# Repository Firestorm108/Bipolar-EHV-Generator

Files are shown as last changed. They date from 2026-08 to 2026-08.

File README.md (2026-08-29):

# Bipolar-EHV-Generator
An extreme high voltage generator that utilizes a bipolar setup to effectively create a 300kV+ voltage difference.

Assembly_2026-Aug-29_12-14-39AM-000_CustomizedView10577367450

# How does it work?

The custom ZVS driver drives the self-wound HV AC transformer. That transformer is connected to both inputs of voltage mulitpliers.
By configuring each multiplier to output a +HV and the other to do a -HV, it is no longer a +HV - GND difference, but +HV -HV difference.

Screenshot 2026-08-28 at 5 43 17 PM

# PCB Pictures

Screenshot 2026-08-28 at 5 44 21 PM
Screenshot 2026-08-28 at 5 44 59 PM

# Bill of Materials

| Item | Price | Link |
| --- | ---: | --- |
| White PLA | $13 | [Amazon](https://www.amazon.com/SUNLU-Printer-Filament-1-75mm-Printers/dp/B0BD7K5SQK/) |
| Kapton Tape | $10 | [Amazon](https://www.amazon.com/Hxtape-Temperature-Polyimide-Printing-Soldering/dp/B07D5RRXTS/) |
| 32 AWG Magnet Wire | $13 | [Amazon](https://www.amazon.com/BNTECHGO-AWG-Magnet-Wire-Transformers/dp/B07JBQQR38/) |
| Transformer Core | $23 | [Amazon](https://www.amazon.com/5pairs-UY1658-Transformer-ferrite-Material/dp/B0146OG8VK/r) |
| 16 AWG | $8 | [Amazon](https://www.amazon.com/Silicone-Electrical-Cable%EF%BC%8810ft-Temperature-Resistant/dp/B0D93K21TN/) |
| Momentary Push Button | $3 | [AliExpress](https://www.aliexpress.us/item/3256812230348809.html) |
| 40 × 2CL77 Diodes | $13 | [AliExpress](https://www.aliexpress.us/item/3256802425242911.html) |
| 40 × 20 kV 1 nF Capacitors | $14 | [AliExpress](https://www.aliexpress.us/item/3256809649447491.html) |
| 24 V 20 A SMPS | $22 | [Amazon](https://www.amazon.com/HPMN-24V-15A-360W-Transformer/dp/B0DPKJPB5P) |
| Mains Cable | $4 | [AliExpress](https://www.aliexpress.us/item/3256802936747637.html) |
| IRFP250 MOSFETs | $6 | [AliExpress](https://www.aliexpress.us/item/3256806932452420.html) |
| 470 Ω 2 W Resistors | $2 | [AliExpress](https://www.aliexpress.us/item/3256802900888178.html) |
| 0.47 µH 10 A Inductor | $6 | [AliExpress](https://www.aliexpress.us/item/3256806537093956.html) |
| 2-Pin Screw Terminals | $3 | [AliExpress](https://www.aliexpress.us/item/3256806674476213.html) |
| 3-Pin Screw Terminals | $4 | [AliExpress](https://www.aliexpress.us/item/3256806674476213.html) |
| 1N4742A 12 V Zener Diodes | $1 | [AliExpress](https://www.aliexpress.us/item/2255799836200735.html) |
| UF4007 400 V Fast-Switching Diodes | $2 | [AliExpress](https://www.aliexpress.us/item/2255800018624086.html) |
| 0.68 µF Film Capacitors | $3 | [AliExpress](https://www.aliexpress.us/item/3256801916333851.html) |
| 50 V 1000 µF Electrolytics | $5 | [AliExpress](https://www.aliexpress.us/item/3256811625053645.html) |
| Multiplier PCB | $8 | JLCPCB |
| ZVS PCB | $16 | JLCPCB |
| JLC Shipping | $15 | JLCPCB |
| **Total** | **$194** | |

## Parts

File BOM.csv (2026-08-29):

Item | Price | Link
White PLA | $13 | https://www.amazon.com/SUNLU-Printer-Filament-1-75mm-Printers/dp/B0BD7K5SQK/
Kapton Tape | $10 | https://www.amazon.com/Hxtape-Temperature-Polyimide-Printing-Soldering/dp/B07D5RRXTS/
32AWG Magnet Wire | $13 | https://www.amazon.com/BNTECHGO-AWG-Magnet-Wire-Transformers/dp/B07JBQQR38/
Transformer Core | $23 | https://www.amazon.com/5pairs-UY1658-Transformer-ferrite-Material/dp/B0146OG8VK/r
16 AWG | $8 | https://www.amazon.com/Silicone-Electrical-Cable%EF%BC%8810ft-Temperature-Resistant/dp/B0D93K21TN/
Momentary Push Button | $3 | https://www.aliexpress.us/item/3256812230348809.html?
40 2CL77 Diodes | $13 | https://www.aliexpress.us/item/3256802425242911.html
40 20kV 1nF Capacitors | $14 | https://www.aliexpress.us/item/3256809649447491.html
24V 20A SMPS | $22 | https://www.amazon.com/HPMN-24V-15A-360W-Transformer/dp/B0DPKJPB5P
Mains Cable | $4 | https://www.aliexpress.us/item/3256802936747637.html
IRFP250 MOSFETs | $6 | https://www.aliexpress.us/item/3256806932452420.html?
470 Ohm 2W Resistors | $2 | https://www.aliexpress.us/item/3256802900888178.html?
0.47uH 10A Inductor | $6 | https://www.aliexpress.us/item/3256806537093956.html
2 Pin Screw Terminals | $3 | https://www.aliexpress.us/item/3256806674476213.html
3 Pin Screw Terminals | $4 | https://www.aliexpress.us/item/3256806674476213.html
1N4742A 12V Zener Diodes | $1 | https://www.aliexpress.us/item/2255799836200735.html?
UF4007 400V Fast Switching Diodes | $2 | https://www.aliexpress.us/item/2255800018624086.html?
0.68uF Film Capacitors | $3 | https://www.aliexpress.us/item/3256801916333851.html
50V 1000uF Electrolytics | $5 | https://www.aliexpress.us/item/3256811625053645.html?
Multiplier PCB | $8 | JLCPCB
ZVS PCB | $16 | JLCPCB
JLC Shipping | $15 | JLCPCB
Total | $194

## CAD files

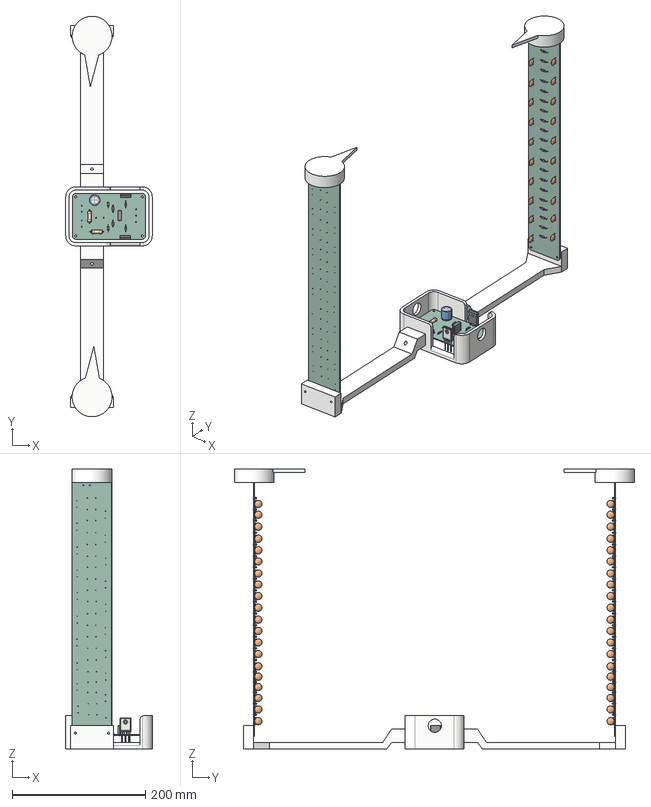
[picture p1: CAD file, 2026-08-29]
Assembly.step
130.1 x 602.1 x 421.0 mm

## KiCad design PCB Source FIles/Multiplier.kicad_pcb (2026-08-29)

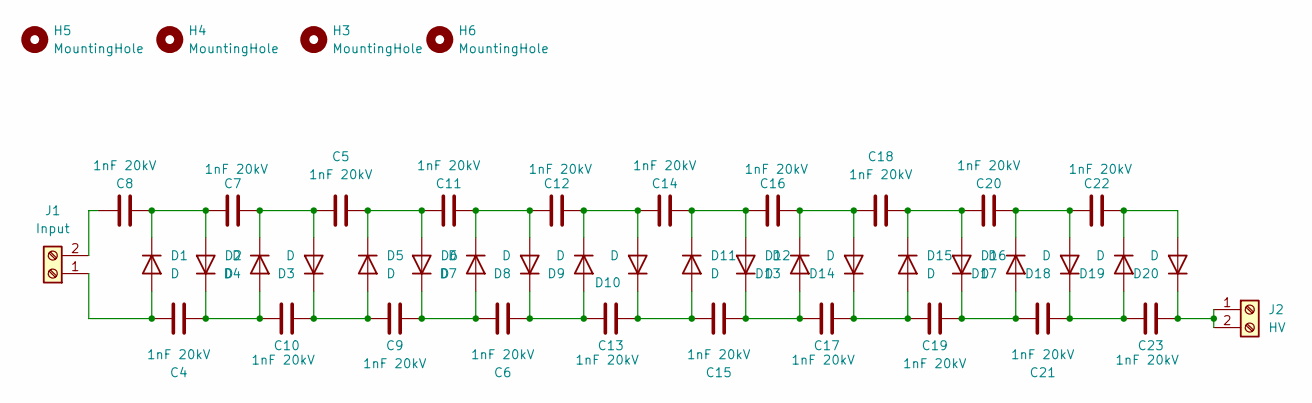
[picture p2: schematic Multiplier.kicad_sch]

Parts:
C4, C5, C6, C7, C8, C9, C10, C11, C12, C13, C14, C15, C16, C17, C18, C19, C20, C21, C22, C23: 1nF 20kV; C_Disc_D11.0mm_W5.0mm_P10.00mm
D1, D2, D3, D4, D5, D6, D7, D8, D9, D10, D11, D12, D13, D14, D15, D16, D17, D18, D19, D20: D; D_DO-41_SOD81_P12.70mm_Horizontal
H3, H4, H5, H6: MountingHole; MountingHole_3.2mm_M3
J1: Input; CONN-TH_2P-P9.50_HB9500-9.5-2P
J2: HV; CONN-TH_2P-P9.50_HB9500-9.5-2P

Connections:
unnamed: C4.2, D1.2 (A), J1.1
unnamed: C7.2, C8.1, D1.1 (K), D2.2 (A)
unnamed: C4.1, C10.1, D2.1 (K), D4.2 (A)
unnamed: C5.1, C7.1, D3.2 (A), D4.1 (K)
unnamed: C9.1, C10.2, D3.1 (K), D5.2 (A)
unnamed: C5.2, C11.2, D5.1 (K), D6.2 (A)
unnamed: C6.2, C9.2, D6.1 (K), D7.2 (A)
unnamed: C11.1, C12.2, D7.1 (K), D8.2 (A)
unnamed: C6.1, C13.1, D8.1 (K), D9.2 (A)
unnamed: C12.1, C14.2, D9.1 (K), D10.2 (A)
unnamed: C13.2, C15.2, D10.1 (K), D11.2 (A)
unnamed: C14.1, C16.2, D11.1 (K), D12.2 (A)
unnamed: C15.1, C17.1, D12.1 (K), D13.2 (A)
unnamed: C16.1, C18.1, D13.1 (K), D14.2 (A)
unnamed: C17.2, C19.1, D14.1 (K), D15.2 (A)
unnamed: C18.2, C20.2, D15.1 (K), D16.2 (A)
unnamed: C19.2, C21.2, D16.1 (K), D17.2 (A)
unnamed: C20.1, C22.2, D17.1 (K), D18.2 (A)
unnamed: C21.1, C23.1, D18.1 (K), D19.2 (A)
unnamed: C22.1, D19.1 (K), D20.2 (A)
unnamed: C23.2, D20.1 (K), J2.1, J2.2
unnamed: C8.2, J1.2

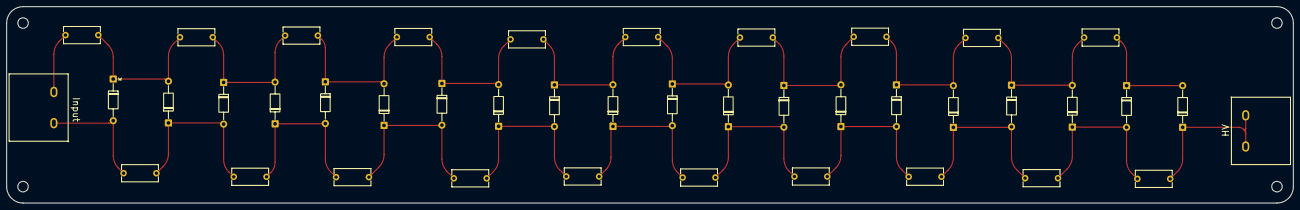
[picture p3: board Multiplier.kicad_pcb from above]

Board: 2 copper layers, 392.1 x 59.8 mm, 46 parts (0 on the bottom side), 22 nets.

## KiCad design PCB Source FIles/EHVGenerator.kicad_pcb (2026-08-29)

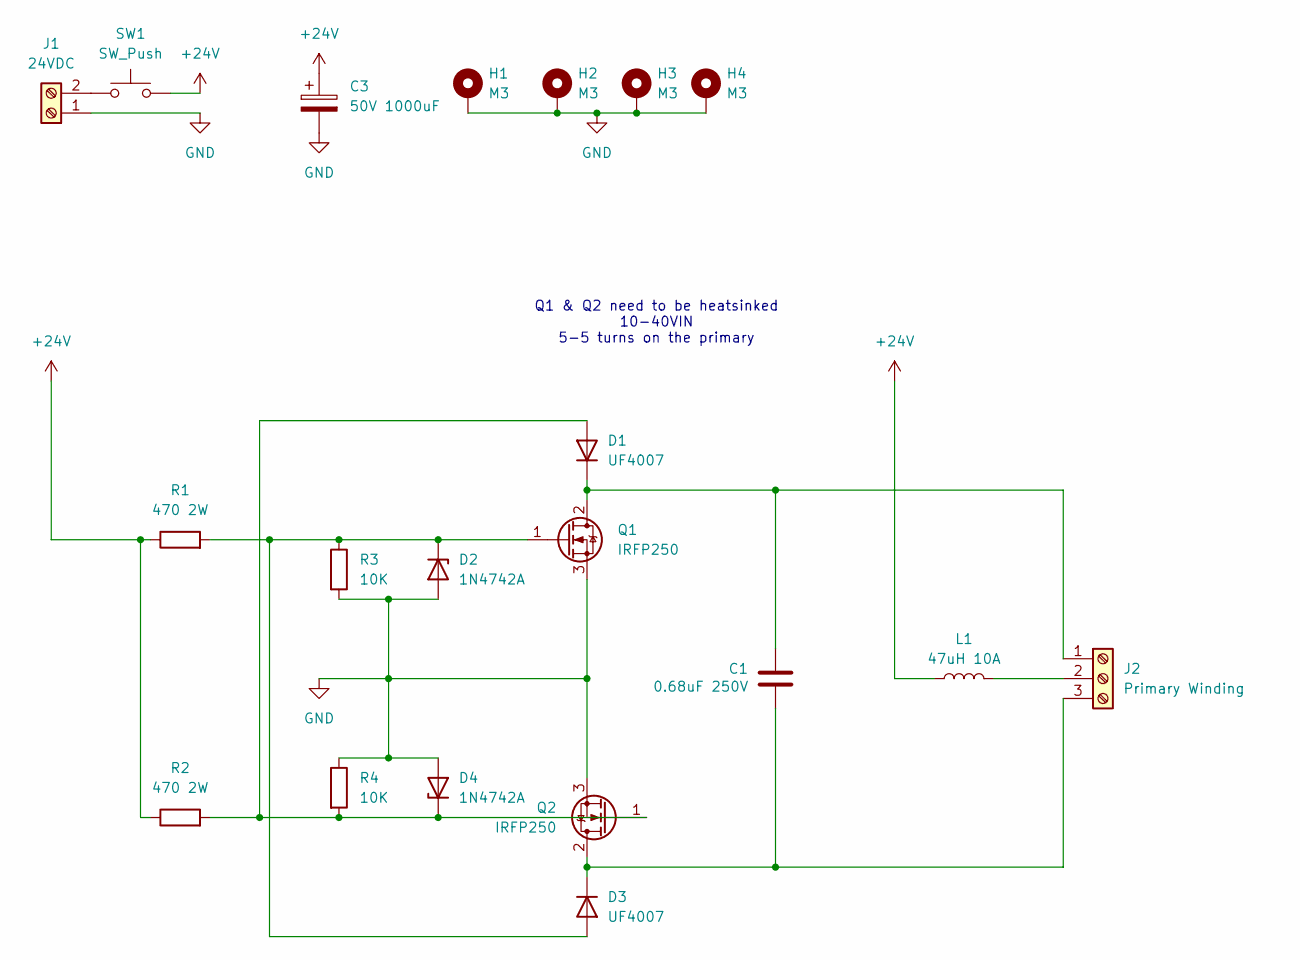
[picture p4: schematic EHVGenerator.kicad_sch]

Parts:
C1: 0.68uF 250V; C_Rect_L16.5mm_W5.0mm_P15.00mm_MKT
C3: 50V 1000uF; CP_Radial_D16.0mm_P7.50mm
D1, D3: UF4007; D_DO-41_SOD81_P10.16mm_Horizontal
D2, D4: 1N4742A; D_DO-41_SOD81_P10.16mm_Horizontal
H1, H2, H3, H4: M3; MountingHole_3.2mm_M3_Pad
J1: 24VDC; CONN-TH_2P-P9.50_HB9500-9.5-2P
J2: Primary Winding; CONN-TH_3P-P9.50_HB9500-9.5-3P
L1: 47uH 10A; L_Toroid_Vertical_L28.6mm_W14.3mm_P11.43mm_Bourns_5700
Q1, Q2: IRFP250; TO-247-3_Vertical
R1, R2: 470 2W; R_Axial_DIN0617_L17.0mm_D6.0mm_P20.32mm_Horizontal
R3, R4: 10K; R_Axial_DIN0207_L6.3mm_D2.5mm_P10.16mm_Horizontal
SW1: SW_Push; CONN-TH_2P-P9.50_HB9500-9.5-2P

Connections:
+24V: C3.1, L1.1, R1.1, R2.1, SW1.2
GND: C3.2, D2.2 (A), D4.2 (A), H1.1 (1_1), H2.1 (1_1), H3.1 (1_1), H4.1 (1_1), J1.1, Q1.3 (S), Q2.3 (S), R3.2, R4.1
unnamed: D1.2 (A), D4.1 (K), Q2.1 (G), R2.2, R4.2
unnamed: C1.2, D1.1 (K), J2.1, Q1.2 (D)
unnamed: D2.1 (K), D3.2 (A), Q1.1 (G), R1.2, R3.1
unnamed: C1.1, D3.1 (K), J2.3, Q2.2 (D)
unnamed: J1.2, SW1.1
unnamed: J2.2, L1.2

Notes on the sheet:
Q1 & Q2 need to be heatsinked 10-40VIN 5-5 turns on the primary

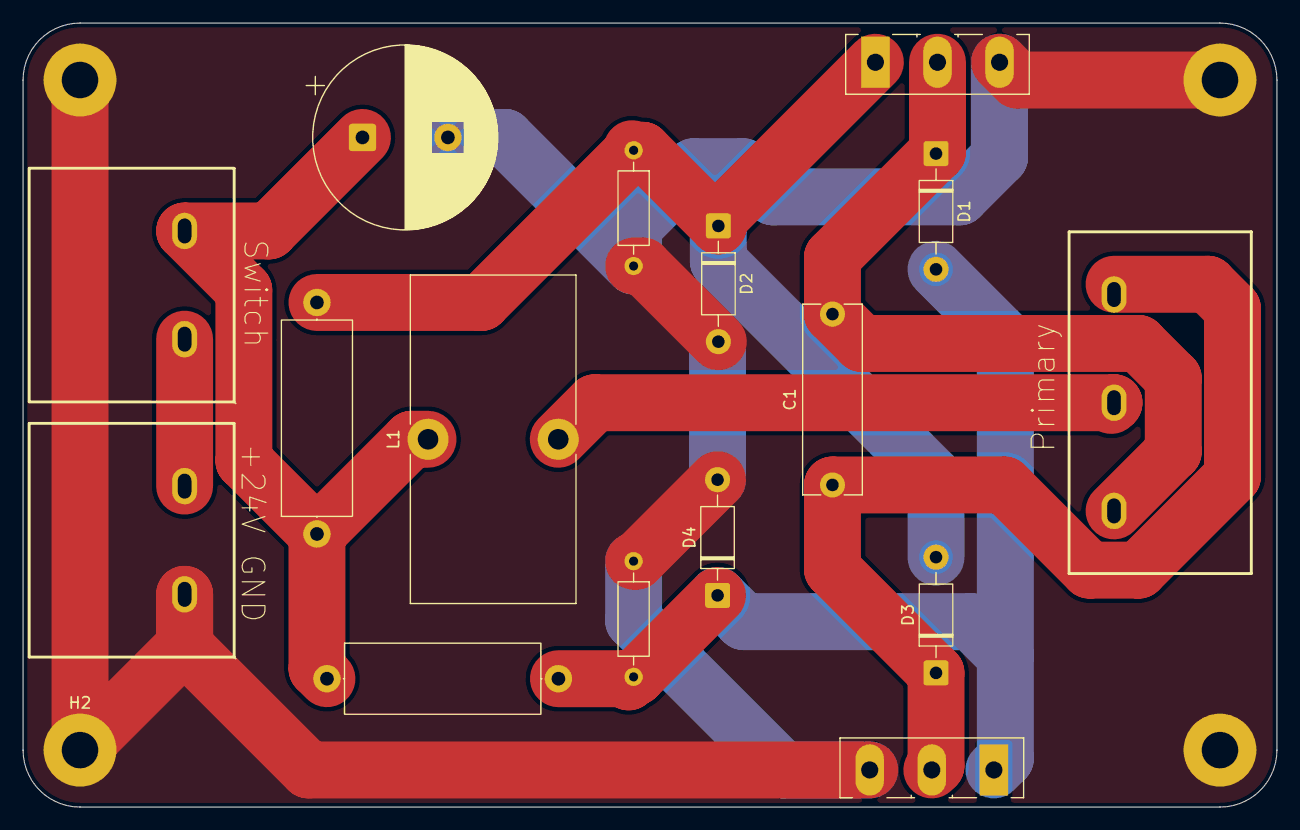
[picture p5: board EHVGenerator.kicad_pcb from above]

Board: 2 copper layers, 110.1 x 68.8 mm, 20 parts (0 on the bottom side), 8 nets.

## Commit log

2026-08-29 Add image to README for assembly reference
    Added an image to the README for visual reference.
2026-08-29 Replace placeholder image with actual assembly image
    Updated image in README to display the assembly view.
2026-08-29 Rename EHV BOM - Sheet1.csv to BOM.csv
    [BOM.csv]
